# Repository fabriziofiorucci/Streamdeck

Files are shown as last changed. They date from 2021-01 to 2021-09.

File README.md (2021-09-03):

# Streamdeck
3D printed USB streamdeck

This project is a remake of https://www.thingiverse.com/thing:4186055 based on an Arduino Pro Micro and HID capabilities

My current keys assignment (under Linux) is the following: it can be fully customized by printing the relevant keycaps and configuring the shortcuts using your preferred OS.

```
1       mute mic
2       mute speaker
3       audio pause
4       audio prev
5       audio next
6       volume down
7       volume up
8       screen capture
9       window capture
10      spectacle
11      keyboard layout switcher
12      custom key 1
13      custom key 2
14      run konsole
15      screensaver
```

Hardware BoM is
- Arduino pro micro (https://www.aliexpress.com/item/32989454699.html)
- 0.96" 128x32 pixels OLED display (https://www.aliexpress.com/item/32672229793.html)
- 3 and 4 pins JST XH2.54 cables and terminals (https://www.aliexpress.com/item/32968520253.html and https://www.aliexpress.com/item/4000801004876.html)
- 4x M3x8mm screws
- Micro USB to USB cable
- Cherry MX switches (https://www.aliexpress.com/item/4000406734661.html)

STL files should be printed using 0.1mm layer height and 3 walls

On thingiverse: https://www.thingiverse.com/thing:4737914

Libraries needed to compile the sketch are:
- https://www.arduino.cc/reference/en/libraries/adafruit-ssd1306/
- https://www.arduino.cc/reference/en/libraries/adafruit-gfx-library/
- https://www.arduino.cc/reference/en/libraries/keypad/

Important notes:
- Stream_deck_body.stl, keys_plate_v6.stl and SSD1306_lid.stl must be printed for the final assembly as in the photographs.
- Case Remix v5.stl is for macro_keypad_top_large_PCB.stl, I didn't try to print it as I don't have this specific keypad. If you happen to print it, please let me know if it fits well.

# Images

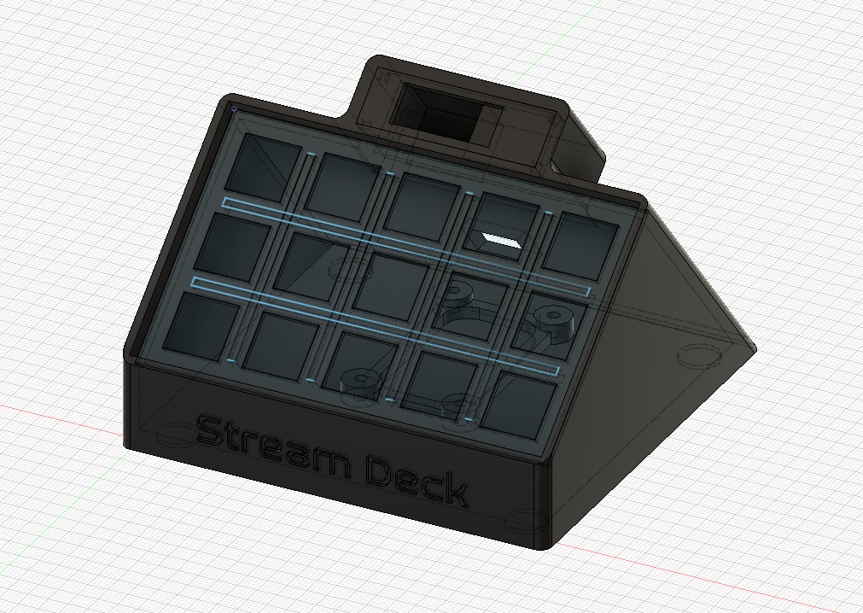
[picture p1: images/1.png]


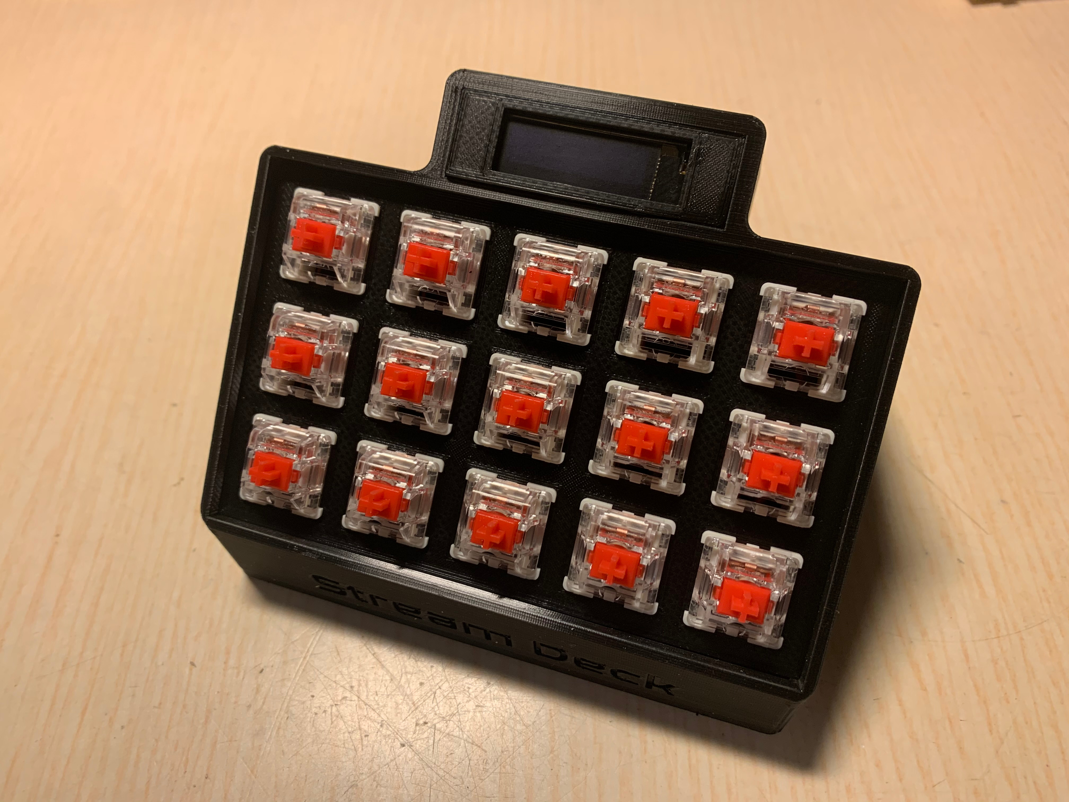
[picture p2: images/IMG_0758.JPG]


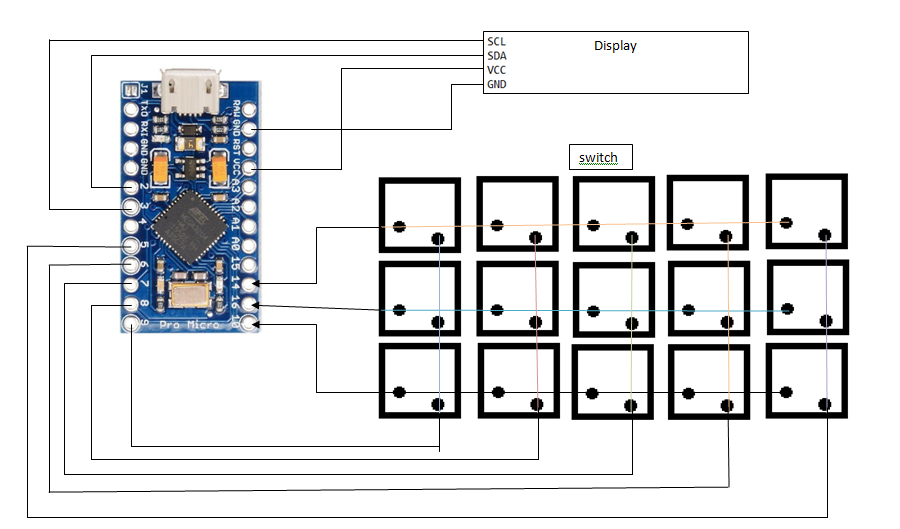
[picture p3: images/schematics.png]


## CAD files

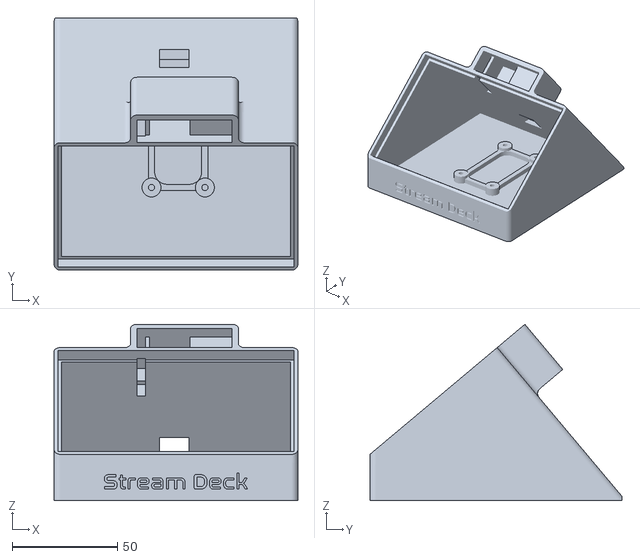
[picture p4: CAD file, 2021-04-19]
CAD/stl/Case Remix v5.stl
116.0 x 119.9 x 83.8

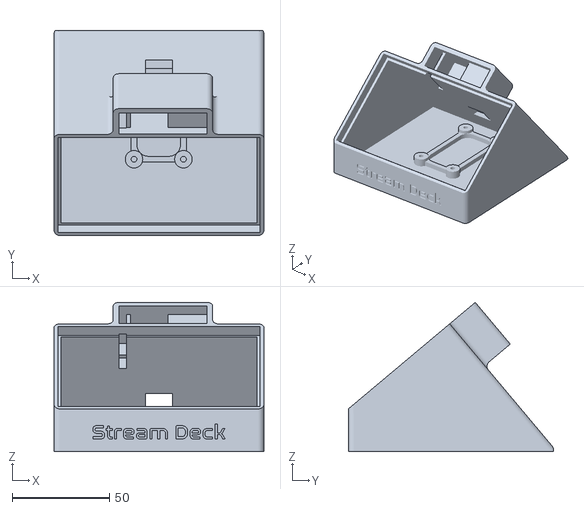
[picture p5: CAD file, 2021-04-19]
CAD/stl/Stream deck body.stl
108.0 x 105.6 x 76.8

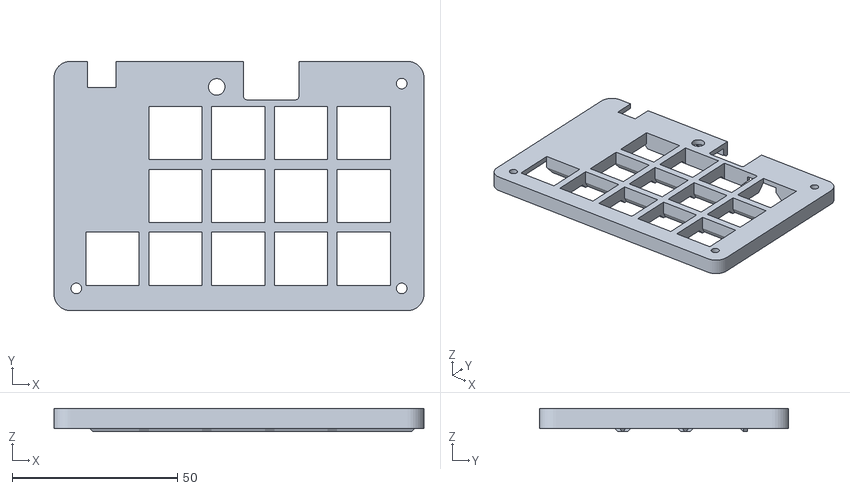
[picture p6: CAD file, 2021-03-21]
CAD/stl/macro_keypad_top_large_PCB.stl
112.0 x 75.5 x 7.00

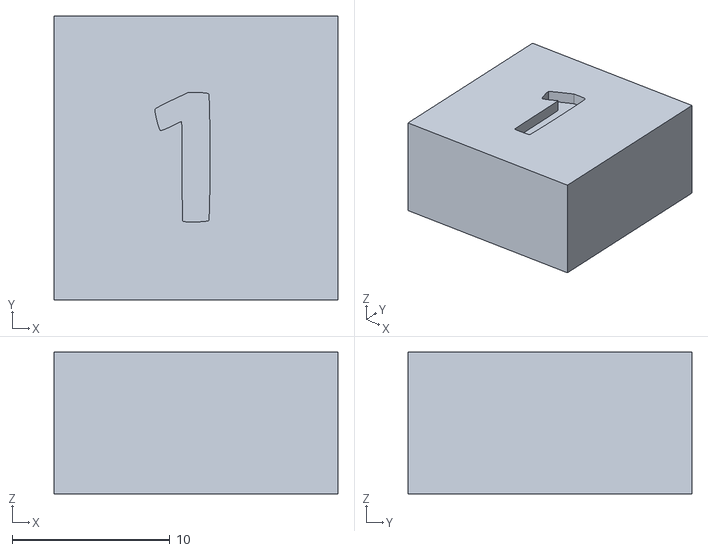
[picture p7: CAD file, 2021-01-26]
CAD/stl/Custom 1 v2.stl
18.0 x 18.0 x 9.00

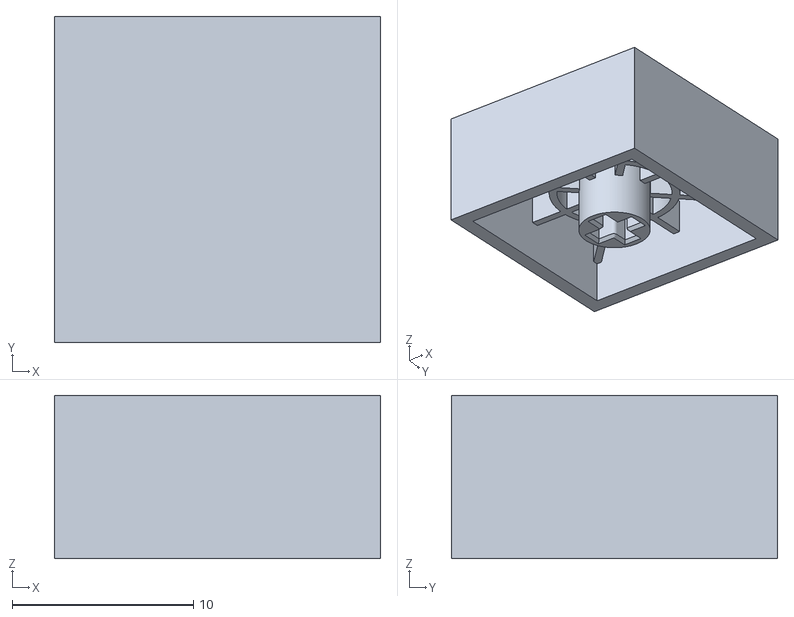
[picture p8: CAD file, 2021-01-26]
CAD/stl/Flat keycap v2.stl
18.0 x 18.0 x 9.00

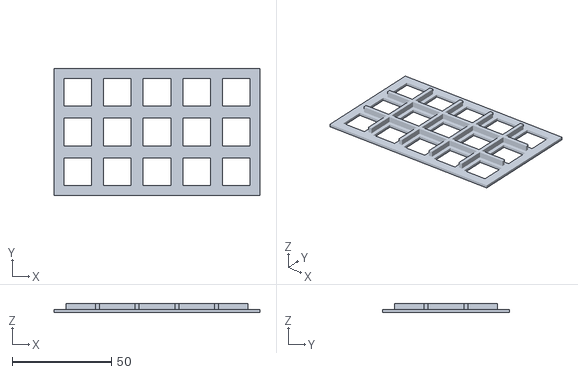
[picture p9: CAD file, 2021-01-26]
CAD/stl/keys plate v6.stl
104.0 x 64.0 x 4.50

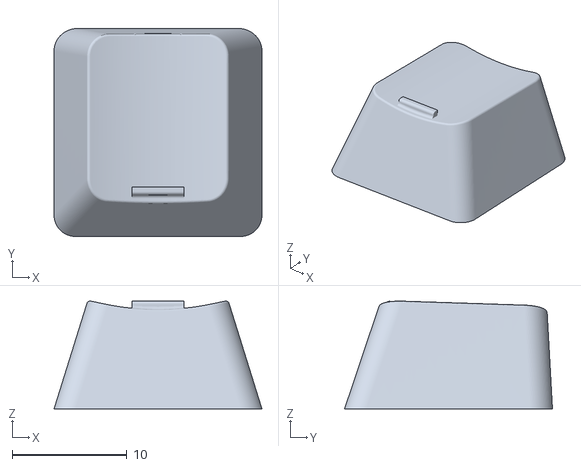
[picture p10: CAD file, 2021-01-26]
CAD/stl/kc0001 v9 v2.stl
18.1 x 18.1 x 9.41

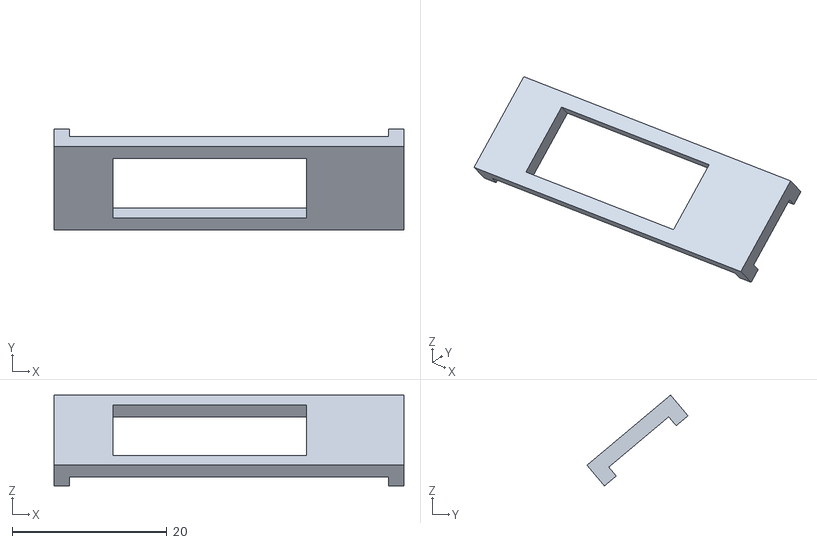
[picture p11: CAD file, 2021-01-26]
CAD/stl/SSD1306 lid.stl
45.2 x 13.1 x 11.7

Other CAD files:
CAD/stl/Mic mute v2.stl
CAD/stl/Lock v2.stl
CAD/stl/Audio mute v9.stl
CAD/stl/Volume down v3.stl
CAD/stl/Playpause v4.stl
CAD/stl/Keyboard v2.stl
CAD/stl/Volume up v2.stl
CAD/stl/Screenshot v4.stl
CAD/stl/Konsole v2.stl
CAD/stl/Custom 2 v2.stl
CAD/f3d/Flat keycap v2.f3d
CAD/stl/Forward-Reverse v2.stl

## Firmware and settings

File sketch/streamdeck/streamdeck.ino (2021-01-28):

/*
  https://miliohm.com/complete-tutorial-for-i2c-oled-0-96-128x64-arduino-display/
*/

//#define HID_CUSTOM_LAYOUT // set this flag to indicate that a custom layout is selected
// if the above flag is not defined, then the default US layout is used instead

//#define LAYOUT_ITALIAN // set this flag after the above flag to indicate the custom input method is German
// for more layouts, see /src/KeyboardLayouts/ImprovedKeylayouts.h

// you must set the above flags before including HID-Project
#include "HID-Project.h"

#include <SPI.h>
#include <Wire.h>
#include <Adafruit_GFX.h>
#include <Adafruit_SSD1306.h>
#include <Keypad.h>

const byte ROWS = 3; //four rows
const byte COLS = 5; //four columns
//define the cymbols on the buttons of the keypads
char hexaKeys[ROWS][COLS] = {
  {'0','1','2','3','4'},
  {'5','6','7','8','9'},
  {'A','B','C','D','E'}
};
byte rowPins[ROWS] = {14,16,10}; //connect to the row pinouts of the keypad
byte colPins[COLS] = {5,6,7,8,9}; //connect to the column pinouts of the keypad

//initialize an instance of class NewKeypad
Keypad customKeypad = Keypad( makeKeymap(hexaKeys), rowPins, colPins, ROWS, COLS); 

#define SCREEN_WIDTH 128 // OLED display width, in pixels
#define SCREEN_HEIGHT 32 // OLED display height, in pixels

// Declaration for an SSD1306 display connected to I2C (SDA, SCL pins)
// The pins for I2C are defined by the Wire-library. 
// On an arduino UNO:       A4(SDA), A5(SCL)
// On an arduino MEGA 2560: 20(SDA), 21(SCL)
// On an arduino LEONARDO:   2(SDA),  3(SCL), ...
#define OLED_RESET     4 // Reset pin # (or -1 if sharing Arduino reset pin)
Adafruit_SSD1306 display(SCREEN_WIDTH, SCREEN_HEIGHT, &Wire, OLED_RESET);

static const unsigned char PROGMEM bitmap_audiomute[] =
{
  B00000000, B00000000, B00000010, B00000000, B00000000, B00000000, B00000000, B00000000, B00000000, B00000000, B00000000, B00000000, B00000000, B00000000, B00000011, B11000000,
  B00000000, B00000000, B00000110, B00000000, B00000000, B00000000, B00000000, B00000000, B00000000, B00000000, B00000000, B00000000, B00000000, B00000000, B00000011, B11000000,
  B00000000, B00000000, B00111110, B00000000, B00000000, B00000000, B00000000, B00000000, B00000000, B00000000, B00000000, B00000000, B00000000, B00000000, B00000011, B11000000,
  B00000000, B00000000, B01111110, B00000000, B00000000, B00000000, B00000000, B00000000, B00000000, B00000000, B00000000, B00000000, B00000000, B00000000, B00000011, B11000000,
  B00000000, B00000001, B11111110, B00000000, B00000000, B00000000, B00000000, B00000000, B00000000, B00000000, B00000000, B00000000, B00000000, B00000000, B00000011, B11000000,
  B00000000, B00000011, B11100110, B00000000, B00000000, B00000000, B00000000, B00000000, B00000000, B00000000, B00000000, B00000000, B00000000, B00000000, B00000011, B11000000,
  B00000000, B00001111, B10000110, B00000000, B00000000, B00000000, B00000000, B00000000, B00000000, B00000000, B00000000, B00000000, B00000000, B00000000, B00000011, B11000000,
  B00000000, B00011111, B00000110, B00000000, B00000000, B00000000, B00011111, B00000011, B11100000, B00000000, B00000000, B00000000, B00000000, B00000000, B00000011, B11000000,
  B00111111, B11111100, B00000110, B00000000, B00000000, B00000000, B00011111, B00000111, B11100000, B00000000, B00000000, B00000000, B00000000, B00000000, B00000011, B11000000,
  B01111111, B11111000, B00000110, B00000000, B00000000, B00000000, B00011111, B10000111, B11100000, B00000000, B00000001, B11100000, B00000000, B00000000, B00000011, B11000000,
  B11111111, B11100000, B00000110, B00011000, B00000110, B00000000, B00111111, B10000111, B11100000, B00000000, B00000001, B11100000, B00000000, B00000000, B00000011, B11000000,
  B11100000, B11100000, B00000110, B00111100, B00001111, B00000000, B00111111, B10001111, B11100000, B00000000, B00000001, B11100000, B00000000, B00000000, B00000011, B11000000,
  B11100000, B11100000, B00000110, B00011110, B00011110, B00000000, B00111111, B11001111, B11100000, B11110000, B11110111, B11111000, B00111111, B00000000, B11111011, B11000000,
  B11100000, B11100000, B00000110, B00001111, B00111100, B00000000, B00111111, B11001111, B11110000, B11110000, B11110111, B11111000, B11111111, B10000001, B11111111, B11000000,
  B11100000, B11100000, B00000110, B00000111, B11111000, B00000000, B00111111, B11011111, B11110000, B11110000, B11110111, B11111001, B11111111, B11000011, B11111111, B11000000,
  B11100000, B11100000, B00000110, B00000011, B11110000, B00000000, B00111101, B11111110, B11110000, B11110000, B11110111, B11111001, B11100001, B11100111, B11101111, B11000000,
  B11100000, B11100000, B00000110, B00000011, B11110000, B00000000, B01111101, B11111110, B11110000, B11110000, B11110001, B11100001, B11100001, B11100111, B11000111, B11000000,
  B11100000, B11100000, B00000110, B00000111, B11111000, B00000000, B01111101, B11111100, B11110000, B11110000, B11110001, B11100011, B11111111, B11100111, B10000011, B11000000,
  B11100000, B11100000, B00000110, B00001111, B00111100, B00000000, B01111100, B11111100, B11111000, B11110000, B11110001, B11100011, B11111111, B11100111, B10000011, B11000000,
  B11100000, B11100000, B00000110, B00011110, B00011110, B00000000, B01111000, B11111100, B11111000, B11110000, B11110001, B11100011, B11100000, B00000111, B10000011, B11000000,
  B11100000, B11100000, B00000110, B00111100, B00001111, B00000000, B01111000, B11111000, B11111000, B11110001, B11110001, B11100001, B11100001, B11100111, B11100111, B11000000,
  B11111111, B11100000, B00000110, B00011000, B00000110, B00000000, B01111000, B01111000, B11111000, B11111111, B11110001, B11100001, B11111111, B11100011, B11111111, B11000000,
  B01111111, B11111000, B00000110, B00000000, B00000000, B00000000, B11111000, B01110000, B01111000, B11111111, B11100001, B11100000, B11111111, B11000011, B11111111, B11000000,
  B00111111, B11111100, B00000110, B00000000, B00000000, B00000000, B11111000, B00110000, B01111000, B01111111, B11000001, B11100000, B01111111, B10000001, B11111111, B11000000,
  B00000000, B00011111, B00000110, B00000000, B00000000, B00000000, B00000000, B00000000, B00000000, B00000000, B00000000, B00000000, B00000000, B00000000, B00000000, B00000000,
  B00000000, B00001111, B10000110, B00000000, B00000000, B00000000, B00000000, B00000000, B00000000, B00000000, B00000000, B00000000, B00000000, B00000000, B00000000, B00000000,
  B00000000, B00000011, B11100110, B00000000, B00000000, B00000000, B00000000, B00000000, B00000000, B00000000, B00000000, B00000000, B00000000, B00000000, B00000000, B00000000,
  B00000000, B00000001, B11111110, B00000000, B00000000, B00000000, B00000000, B00000000, B00000000, B00000000, B00000000, B00000000, B00000000, B00000000, B00000000, B00000000,
  B00000000, B00000000, B01111110, B00000000, B00000000, B00000000, B00000000, B00000000, B00000000, B00000000, B00000000, B00000000, B00000000, B00000000, B00000000, B00000000,
  B00000000, B00000000, B00111110, B00000000, B00000000, B00000000, B00000000, B00000000, B00000000, B00000000, B00000000, B00000000, B00000000, B00000000, B00000000, B00000000,
  B00000000, B00000000, B00000110, B00000000, B00000000, B00000000, B00000000, B00000000, B00000000, B00000000, B00000000, B00000000, B00000000, B00000000, B00000000, B00000000,
  B00000000, B00000000, B00000010, B00000000, B00000000, B00000000, B00000000, B00000000, B00000000, B00000000, B00000000, B00000000, B00000000, B00000000, B00000000, B00000000
};

static const unsigned char PROGMEM bitmap_audiovolumeup[] =
{
  B00000000, B00000000, B00000010, B00000000, B00000000, B00000000, B00000000, B00000000, B00000000, B00000000, B00000000, B00000000, B00000000, B00000000, B00000000, B00000000,
  B00000000, B00000000, B00000110, B00000000, B00000000, B00000000, B00000000, B00000000, B00000000, B00000000, B00000000, B00000000, B00000000, B00000000, B00000000, B00000000,
  B00000000, B00000000, B00111110, B00000000, B00000000, B00000000, B00000000, B00000000, B00000000, B00000000, B00000000, B00000000, B00000000, B00000000, B00000000, B00000000,
  B00000000, B00000000, B01111110, B00000000, B00000000, B00000000, B00000000, B00000000, B00000000, B00000000, B00000000, B00000000, B00000000, B00000000, B00000000, B00000000,
  B00000000, B00000001, B11111110, B00000000, B00000000, B00000000, B00000000, B00000000, B00000000, B00000000, B00000000, B00000000, B00000000, B00000000, B00000000, B00000000,
  B00000000, B00000011, B11100110, B00000000, B00000000, B00000000, B00000000, B00000000, B00000000, B00000000, B00000000, B00000000, B00000000, B00000000, B00000000, B00000000,
  B00000000, B00001111, B10000110, B00000000, B00000000, B00000000, B00000000, B00000000, B00000000, B00000000, B00000000, B00000000, B00000000, B00000000, B00000000, B00000000,
  B00000000, B00011111, B00000110, B00000000, B00000000, B00000000, B00000000, B00000000, B00000000, B00000000, B00000000, B00000000, B00000000, B00000000, B00000000, B00000000,
  B00111111, B11111100, B00000110, B00000000, B00000000, B00000000, B00000000, B00000000, B00000000, B00000000, B00000000, B00000000, B00000000, B00000000, B00000000, B00000000,
  B01111111, B11111000, B00000110, B00000000, B00000000, B00000000, B00000000, B00000000, B00000000, B00000000, B00000000, B00000000, B00000000, B00000000, B00000000, B00000000,
  B11111111, B11100000, B00000110, B00000000, B11000000, B00000000, B00000000, B00000000, B00000000, B00000000, B00000000, B00000000, B00000000, B00000000, B00000000, B00000000,
  B11100000, B11100000, B00000110, B00000000, B11000000, B00000000, B00000000, B00000000, B00000000, B00000000, B00000000, B00000000, B00000000, B00000000, B00000000, B00000000,
  B11100000, B11100000, B00000110, B00000000, B11000000, B00000000, B00000000, B00000000, B00000000, B00000000, B00000000, B00000000, B00000000, B00000000, B00000000, B00000000,
  B11100000, B11100000, B00000110, B00000000, B11000000, B00000000, B00000000, B00000000, B00000000, B00000000, B00000000, B00000000, B00000000, B00000000, B00000000, B00000000,
  B11100000, B11100000, B00000110, B00000000, B11000000, B00000000, B00000000, B00000000, B00000000, B00000000, B00000000, B00000000, B00000000, B00000000, B00000000, B00000000,
  B11100000, B11100000, B00000110, B00111111, B11111111, B00000000, B00000000, B00000000, B00000000, B00000000, B00000000, B00000000, B00000000, B00000000, B00000000, B00000000,
  B11100000, B11100000, B00000110, B00111111, B11111111, B00000000, B00000000, B00000000, B00000000, B00000000, B00000000, B00000000, B00000000, B00000000, B00000000, B00000000,
  B11100000, B11100000, B00000110, B00000000, B11000000, B00000000, B00000000, B00000000, B00000000, B00000000, B00000000, B00000000, B00000000, B00000000, B00000000, B00000000,
  B11100000, B11100000, B00000110, B00000000, B11000000, B00000000, B00000000, B00000000, B00000000, B00000000, B00000000, B00000000, B00000000, B00000000, B00000000, B00000000,
  B11100000, B11100000, B00000110, B00000000, B11000000, B00000000, B00000000, B00000000, B00000000, B00000000, B00000000, B00000000, B00000000, B00000000, B00000000, B00000000,
  B11100000, B11100000, B00000110, B00000000, B11000000, B00000000, B00000000, B00000000, B00000000, B00000000, B00000000, B00000000, B00000000, B00000000, B00000000, B00000000,
  B11111111, B11100000, B00000110, B00000000, B11000000, B00000000, B00000000, B00000000, B00000000, B00000000, B00000000, B00000000, B00000000, B00000000, B00000000, B00000000,
  B01111111, B11111000, B00000110, B00000000, B00000000, B00000000, B00000000, B00000000, B00000000, B00000000, B00000000, B00000000, B00000000, B00000000, B00000000, B00000000,
  B00111111, B11111100, B00000110, B00000000, B00000000, B00000000, B00000000, B00000000, B00000000, B00000000, B00000000, B00000000, B00000000, B00000000, B00000000, B00000000,
  B00000000, B00011111, B00000110, B00000000, B00000000, B00000000, B00000000, B00000000, B00000000, B00000000, B00000000, B00000000, B00000000, B00000000, B00000000, B00000000,
  B00000000, B00001111, B10000110, B00000000, B00000000, B00000000, B00000000, B00000000, B00000000, B00000000, B00000000, B00000000, B00000000, B00000000, B00000000, B00000000,
  B00000000, B00000011, B11100110, B00000000, B00000000, B00000000, B00000000, B00000000, B00000000, B00000000, B00000000, B00000000, B00000000, B00000000, B00000000, B00000000,
  B00000000, B00000001, B11111110, B00000000, B00000000, B00000000, B00000000, B00000000, B00000000, B00000000, B00000000, B00000000, B00000000, B00000000, B00000000, B00000000,
  B00000000, B00000000, B01111110, B00000000, B00000000, B00000000, B00000000, B00000000, B00000000, B00000000, B00000000, B00000000, B00000000, B00000000, B00000000, B00000000,
  B00000000, B00000000, B00111110, B00000000, B00000000, B00000000, B00000000, B00000000, B00000000, B00000000, B00000000, B00000000, B00000000, B00000000, B00000000, B00000000,
  B00000000, B00000000, B00000110, B00000000, B00000000, B00000000, B00000000, B00000000, B00000000, B00000000, B00000000, B00000000, B00000000, B00000000, B00000000, B00000000,
  B00000000, B00000000, B00000010, B00000000, B00000000, B00000000, B00000000, B00000000, B00000000, B00000000, B00000000, B00000000, B00000000, B00000000, B00000000, B00000000
};

static const unsigned char PROGMEM bitmap_audiovolumedown[] =
{
  B00000000, B00000000, B00000010, B00000000, B00000000, B00000000, B00000000, B00000000, B00000000, B00000000, B00000000, B00000000, B00000000, B00000000, B00000000, B00000000,
  B00000000, B00000000, B00000110, B00000000, B00000000, B00000000, B00000000, B00000000, B00000000, B00000000, B00000000, B00000000, B00000000, B00000000, B00000000, B00000000,
  B00000000, B00000000, B00111110, B00000000, B00000000, B00000000, B00000000, B00000000, B00000000, B00000000, B00000000, B00000000, B00000000, B00000000, B00000000, B00000000,
  B00000000, B00000000, B01111110, B00000000, B00000000, B00000000, B00000000, B00000000, B00000000, B00000000, B00000000, B00000000, B00000000, B00000000, B00000000, B00000000,
  B00000000, B00000001, B11111110, B00000000, B00000000, B00000000, B00000000, B00000000, B00000000, B00000000, B00000000, B00000000, B00000000, B00000000, B00000000, B00000000,
  B00000000, B00000011, B11100110, B00000000, B00000000, B00000000, B00000000, B00000000, B00000000, B00000000, B00000000, B00000000, B00000000, B00000000, B00000000, B00000000,
  B00000000, B00001111, B10000110, B00000000, B00000000, B00000000, B00000000, B00000000, B00000000, B00000000, B00000000, B00000000, B00000000, B00000000, B00000000, B00000000,
  B00000000, B00011111, B00000110, B00000000, B00000000, B00000000, B00000000, B00000000, B00000000, B00000000, B00000000, B00000000, B00000000, B00000000, B00000000, B00000000,
  B00111111, B11111100, B00000110, B00000000, B00000000, B00000000, B00000000, B00000000, B00000000, B00000000, B00000000, B00000000, B00000000, B00000000, B00000000, B00000000,
  B01111111, B11111000, B00000110, B00000000, B00000000, B00000000, B00000000, B00000000, B00000000, B00000000, B00000000, B00000000, B00000000, B00000000, B00000000, B00000000,
  B11111111, B11100000, B00000110, B00000000, B00000000, B00000000, B00000000, B00000000, B00000000, B00000000, B00000000, B00000000, B00000000, B00000000, B00000000, B00000000,
  B11100000, B11100000, B00000110, B00000000, B00000000, B00000000, B00000000, B00000000, B00000000, B00000000, B00000000, B00000000, B00000000, B00000000, B00000000, B00000000,
  B11100000, B11100000, B00000110, B00000000, B00000000, B00000000, B00000000, B00000000, B00000000, B00000000, B00000000, B00000000, B00000000, B00000000, B00000000, B00000000,
  B11100000, B11100000, B00000110, B00000000, B00000000, B00000000, B00000000, B00000000, B00000000, B00000000, B00000000, B00000000, B00000000, B00000000, B00000000, B00000000,
  B11100000, B11100000, B00000110, B00000000, B00000000, B00000000, B00000000, B00000000, B00000000, B00000000, B00000000, B00000000, B00000000, B00000000, B00000000, B00000000,
  B11100000, B11100000, B00000110, B00111111, B11111111, B00000000, B00000000, B00000000, B00000000, B00000000, B00000000, B00000000, B00000000, B00000000, B00000000, B00000000,
  B11100000, B11100000, B00000110, B00111111, B11111111, B00000000, B00000000, B00000000, B00000000, B00000000, B00000000, B00000000, B00000000, B00000000, B00000000, B00000000,
  B11100000, B11100000, B00000110, B00000000, B00000000, B00000000, B00000000, B00000000, B00000000, B00000000, B00000000, B00000000, B00000000, B00000000, B00000000, B00000000,
  B11100000, B11100000, B00000110, B00000000, B00000000, B00000000, B00000000, B00000000, B00000000, B00000000, B00000000, B00000000, B00000000, B00000000, B00000000, B00000000,
  B11100000, B11100000, B00000110, B00000000, B00000000, B00000000, B00000000, B00000000, B00000000, B00000000, B00000000, B00000000, B00000000, B00000000, B00000000, B00000000,
  B11100000, B11100000, B00000110, B00000000, B00000000, B00000000, B00000000, B00000000, B00000000, B00000000, B00000000, B00000000, B00000000, B00000000, B00000000, B00000000,
  B11111111, B11100000, B00000110, B00000000, B00000000, B00000000, B00000000, B00000000, B00000000, B00000000, B00000000, B00000000, B00000000, B00000000, B00000000, B00000000,
  B01111111, B11111000, B00000110, B00000000, B00000000, B00000000, B00000000, B00000000, B00000000, B00000000, B00000000, B00000000, B00000000, B00000000, B00000000, B00000000,
  B00111111, B11111100, B00000110, B00000000, B00000000, B00000000, B00000000, B00000000, B00000000, B00000000, B00000000, B00000000, B00000000, B00000000, B00000000, B00000000,
  B00000000, B00011111, B00000110, B00000000, B00000000, B00000000, B00000000, B00000000, B00000000, B00000000, B00000000, B00000000, B00000000, B00000000, B00000000, B00000000,
  B00000000, B00001111, B10000110, B00000000, B00000000, B00000000, B00000000, B00000000, B00000000, B00000000, B00000000, B00000000, B00000000, B00000000, B00000000, B00000000,
  B00000000, B00000011, B11100110, B00000000, B00000000, B00000000, B00000000, B00000000, B00000000, B00000000, B00000000, B00000000, B00000000, B00000000, B00000000, B00000000,
  B00000000, B00000001, B11111110, B00000000, B00000000, B00000000, B00000000, B00000000, B00000000, B00000000, B00000000, B00000000, B00000000, B00000000, B00000000, B00000000,
  B00000000, B00000000, B01111110, B00000000, B00000000, B00000000, B00000000, B00000000, B00000000, B00000000, B00000000, B00000000, B00000000, B00000000, B00000000, B00000000,
  B00000000, B00000000, B00111110, B00000000, B00000000, B00000000, B00000000, B00000000, B00000000, B00000000, B00000000, B00000000, B00000000, B00000000, B00000000, B00000000,
  B00000000, B00000000, B00000110, B00000000, B00000000, B00000000, B00000000, B00000000, B00000000, B00000000, B00000000, B00000000, B00000000, B00000000, B00000000, B00000000,
  B00000000, B00000000, B00000010, B00000000, B00000000, B00000000, B00000000, B00000000, B00000000, B00000000, B00000000, B00000000, B00000000, B00000000, B00000000, B00000000
};
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
void loop() {
  char customKey = customKeypad.getKey();
  
  if (customKey){
    Serial.println(customKey);

    switch(customKey) {
      case '0':
        // Toggle microphone mute
        keyPressed=KEY_F20;
        bitmapName=bitmap_micmute;
        break;
      case '1':
        // Toggle speaker mute
        keyPressed=KEY_VOLUME_MUTE;
        bitmapName=bitmap_audiomute;
        break;
      case '2':
        // Toggle media play
        consumerKeyPressed=MEDIA_PLAY_PAUSE;
        bitmapName=bitmap_playpause;
        break;
      case '3':
        // Previous media
        consumerKeyPressed=MEDIA_PREVIOUS;
        bitmapName=bitmap_back;
        break;
      case '4':
        // Next media
        consumerKeyPressed=MEDIA_NEXT;
        bitmapName=bitmap_forward;
        break;
      case '5':
        // Volume down
        keyPressed=KEY_VOLUME_DOWN;
        bitmapName=bitmap_audiovolumedown;
        break;
      case '6':
        // Volume up
        keyPressed=KEY_VOLUME_UP;
        bitmapName=bitmap_audiovolumeup;
        break;
      case '7':
        // Full screen screenshot
        keyPressed=KEY_F15;
        bitmapName=bitmap_screenshot;
        break;
      case '8':
        // Active window screenshot
        keyPressed=KEY_F16;
        bitmapName=bitmap_screenshot;
        break;
      case '9':
        // Launch spectacle
        keyPressed=KEY_F17;
        bitmapName=bitmap_spectacle;
        break;
      case 'A':
        // Keyboard layour switcher
        keyPressed=KEY_F18;
        bitmapName=bitmap_layout;
        break;
      case 'B':
        // Custom key
        keyPressed=KEY_F19;
        bitmapName=bitmap_boot;
        break;
      case 'C':
        // Custom key
        keyPressed=KEY_F21;
        bitmapName=bitmap_boot;
        break;
      case 'D':
        // Run konsole
        keyPressed=KEY_F22;
        bitmapName=bitmap_konsole;
        break;
      case 'E':
        // Screen lock
        keyPressed=KEY_F23;
        bitmapName=bitmap_lock;
        break;
      }
  }

  if(keyPressed!=KEY_RESERVED || consumerKeyPressed!=0) {
    displayBitmapFull(bitmapName,0);
    bitmapOffset=1;

    if(keyPressed!=KEY_RESERVED) {
      Keyboard.write(keyPressed);
    } else if (consumerKeyPressed!=0) {
      Keyboard.write(consumerKeyPressed);
    }

    //digitalWrite(LED_BUILTIN, HIGH);
    delay(100); // Simple debounce
    //digitalWrite(LED_BUILTIN, LOW);
    
    keyPressed=KEY_RESERVED;
    consumerKeyPressed=0;
  }

  if ((millis() - lastPollTime) > pollDuration) {
    lastPollTime=millis();

    if(bitmapOffset==OLED_WIDTH) {
      display.clearDisplay();
      display.display();
      bitmapOffset=0;
    } else if(bitmapOffset>0) {
      display.clearDisplay();
      displayBitmapFull(bitmapName,bitmapOffset);
      bitmapOffset+=2;
      display.display();
    }
  }
}

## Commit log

2021-02-28 updated readme with list of required Arduino libraries
2021-03-10 Schematics added
2021-03-21 Added remix to fit a third-party keypad
    [Case Remix v2.stl, macro_keypad_top_large_PCB.stl]
2021-04-19 Added missing keys plate support
    [Case Remix v2.stl, Case Remix v5.stl, Stream deck body.stl]
